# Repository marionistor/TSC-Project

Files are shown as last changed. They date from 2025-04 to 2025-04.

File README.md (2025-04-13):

# OpenBook

OpenBook este un e-book reader open-source, construit pentru consum mic de energie și versatilitate. Folosește microcontrollerul ESP32-C6-WROOM-1-N8, un ecran e-paper, senzori ambientali, ceas în timp real și stocare extinsă, alimentate de o baterie reîncărcabilă.

diagram

## Bill of Materials

| Componentă | Descriere | Link Achiziție | Documentație |
|---|---|---|---|
| ESP32-C6-WROOM-1-N8 | Microcontroler cu Wi-Fi 6, BLE 5.0 | [Mouser](https://ro.mouser.com/ProductDetail/Espressif-Systems/ESP32-C6-WROOM-1-N8) | [Datasheet](https://www.espressif.com/sites/default/files/documentation/esp32-c6-wroom-1_wroom-1u_datasheet_en.pdf) |
| BME680 | Senzor temperatură, umiditate, presiune, VOC | [Mouser](https://ro.mouser.com/ProductDetail/Bosch-Sensortec/BME680) | [Datasheet](https://www.bosch-sensortec.com/media/boschsensortec/downloads/datasheets/bst-bme680-ds001.pdf) |
| DS3231SN | Ceas în timp real | [Mouser](https://ro.mouser.com/ProductDetail/Analog-Devices/DS3231SN) | [Datasheet](https://www.analog.com/media/en/technical-documentation/data-sheets/DS3231.pdf) |
| W25Q512JVEIQ | Memorie Flash 64MB | [Mouser](https://ro.mouser.com/ProductDetail/Winbond/W25Q512JVEIQ) | [Datasheet](https://www.winbond.com/resource-files/W25Q512JV%20SPI%20RevB%2006252019%20KMS.pdf) |
| MicroSD Slot (112A-TAAR-R03) | Slot card microSD | [Mouser](https://ro.mouser.com/ProductDetail/Attend/112A-TAAR-R03) | [Datasheet](https://www.attend.com.tw/data/download/file/112A-TAAR-R03_Spec.pdf) |
| MCP73831T-5ACI/OT | Încărcător baterie | [Mouser](https://ro.mouser.com/ProductDetail/Microchip-Technology/MCP73831T-5ACI-OT) | [Datasheet](https://ww1.microchip.com/downloads/en/DeviceDoc/MCP73831-Family-Data-Sheet-DS20001984H.pdf) |
| MAX17048G+T10 | Indicator nivel baterie | [Mouser](https://ro.mouser.com/ProductDetail/Analog-Devices/MAX17048G%2BT10) | [Datasheet](https://www.analog.com/media/en/technical-documentation/data-sheets/MAX17048-MAX17049.pdf) |
| XC6220A331MR-G | Regulator 3.3V | [Mouser](https://ro.mouser.com/ProductDetail/Torex-Semiconductor/XC6220A331MR-G) | [Datasheet](https://www.torexsemi.com/file/xc6220/XC6220.pdf) |
| USB4110-GF-A | Conector USB-C | [Mouser](https://ro.mouser.com/ProductDetail/GCT/USB4110-GF-A) | [Datasheet](https://gct.co/files/drawings/usb4110.pdf) |
| CPH3225A | Supercondensator pentru ceas | [Mouser](https://ro.mouser.com/ProductDetail/Seiko-Instruments/CPH3225A) | [Datasheet](https://mm.digikey.com/Volume0/opasdata/d220001/medias/docus/6537/rev05-CPHCPM.pdf) |
| DMG2305UX-7 | MOSFET P-Channel | [Mouser](https://ro.mouser.com/ProductDetail/Diodes-Incorporated/DMG2305UX-7) | [Datasheet](https://www.diodes.com/assets/Datasheets/DMG2305UX.pdf) |
| SI1308EDL-T1-GE3 | MOSFET N-Channel | [Mouser](https://ro.mouser.com/ProductDetail/Vishay-Siliconix/SI1308EDL-T1-GE3) | [Datasheet](https://www.vishay.com/docs/63399/si1308edl.pdf) |
| USBLC6-2SC6Y | Protecție ESD USB | [Mouser](https://ro.mouser.com/ProductDetail/STMicroelectronics/USBLC6-2SC6Y) | [Datasheet](https://www.st.com/resource/en/datasheet/usblc6-2.pdf) |
| PGB1010603MR | Protecție ESD | [Mouser](https://ro.mouser.com/ProductDetail/Littelfuse/PGB1010603MR) | [Datasheet](https://www.littelfuse.com/~/media/electronics/datasheets/esd_protection/littelfuse_pulseguard_esd_pgb1_series_datasheet.pdf) |
| BD5229G-TR | Detector tensiune | [Mouser](https://ro.mouser.com/ProductDetail/ROHM-Semiconductor/BD5229G-TR) | [Datasheet](https://fscdn.rohm.com/en/products/databook/datasheet/ic/power/voltage_detector/bd52xxg-e.pdf) |
| FH34SRJ-24S-0.5SH(99) | Conector FFC/FPC e-paper | [Mouser](https://ro.mouser.com/ProductDetail/Hirose-Connector/FH34SRJ-24S-0.5SH99) | [Datasheet](https://www.hirose.com/product/document?clcode=&productname=&series=FH34SRJ&documenttype=Catalog&lang=en) |
| 744043680 | Inductor | [Mouser](https://ro.mouser.com/ProductDetail/Wurth-Elektronik/744043680) | [Datasheet](https://www.we-online.com/components/products/datasheet/744043680.pdf) |
| EVQPUJ02K | Buton tactil | [Mouser](https://ro.mouser.com/ProductDetail/Panasonic/EVQPUJ02K) | [Datasheet](https://www.lcsc.com/datasheet/lcsc_datasheet_2201121800_PANASONIC-EVQPUJ02K_C2936858.pdf) |
| KP-1608SURCK | LED indicator | [Mouser](https://ro.mouser.com/ProductDetail/Kingbright/KP-1608SURCK) | [Datasheet](https://media.elv.com/file/107153_led_surck1608_data.pdf) |

## Funcționalitate Hardware

### 1. Microcontroler ESP32-C6-WROOM-1-N8
* Rol: Gestionează toate funcțiile, de la afișaj la conectivitate wireless
* Specificații: Procesor 32-bit, 160 MHz, 512 KB SRAM, Wi-Fi 6, Bluetooth 5.0
* Conexiuni:
  * SPI: Conectează ecranul, memoria Flash și cardul SD
  * I²C: Interfațează senzorul, ceasul și indicatorul de baterie
  * GPIO: Controlează butoanele și alte funcții
  * UART: Utilizat pentru depanare
* Consum: 3.3V, sub 10 µA în mod repaus

### 2. Ecran E-Paper
* Tip: 7.5 inci, rezoluție 800x480 pixeli
* Conexiune: SPI, cu linii pentru date, control și stare
* Consum: 20-50 mA la reîmprospătare, aproape zero în mod static
* Rol: Afișează text clar, ideal pentru lectură prelungită

### 3. Stocare
* Memorie Flash (W25Q512JVEIQ):
  * Capacitate: 64 MB, conectată prin SPI
  * Scop: Stochează firmware și cărți
  * Consum: 10-20 mA
* Slot MicroSD:
  * Conexiune: SPI, pentru stocare suplimentară
  * Consum: 30-100 mA la citire/scriere

### 4. Ceas în Timp Real (DS3231SN)
* Conexiune: I2C, partajat cu alte module
* Consum: Sub 1 µA cu supercondensator
* Rol: Menține ora exactă pentru loguri sau programări

### 5. Senzor Ambiental (BME680)
* Măsurători: Temperatură, umiditate, presiune, compuși volatili
* Conexiune: I2C, viteză de 400 kHz
* Consum: 0.8-3.6 mA în funcționare, sub 1 µA în repaus
* Rol: Monitorizează mediul pentru ajustări sau date

### 6. Alimentare
* Baterie: Li-Po, 2500 mAh, 3.7V
* Încărcare: MCP73831, maxim 1A prin USB-C
* Monitorizare: MAX17048, consum ~50 µA
* Regulator: 3.3V stabil
* Protecție: Împotriva descărcărilor electrostatice și polarității greșite

### 7. Interfață Utilizator
* Butoane: Trei tactile pentru navigare
* LED: Indică starea dispozitivului

### 8. Extensii
* Conector Qwiic: Pentru senzori I2C suplimentari
* Pini GPIO: Pentru conectarea altor module

## Pini ESP32-C6

| Pin | Semnal | Funcție | Motiv |
|---|---|---|---|
| EN | RESET | Resetare sistem | Pin standard pentru resetare |
| IO0 | INT_RTC | Întrerupere RTC | Capacitate de întrerupere low-power |
| IO1 | 32KHZ | Ieșire ceas RTC 32 kHz | Asigură cronometrare precisă |
| IO2 | MISO | Intrare date SPI | Comun pentru magistrala SPI |
| IO3 | EPD_BUSY | Stare ocupat e-paper | Verifică disponibilitatea afișajului |
| IO4 | SS_SD | Selectare card SD | CS dedicat pentru card SD |
| IO5 | EPD_DC | Date/comenzi e-paper | Distinge datele de comenzi |
| IO6 | SCK | Ceas SPI | Semnal comun de ceas pentru SPI |
| IO7 | MOSI | Ieșire date SPI | Comun pentru periferice SPI |
| IO9 | IO/BOOT | Buton pornire | Inițiază modul boot sau pornire |
| IO10 | EPD_CS | Selectare e-paper | CS dedicat pentru afișaj |
| IO11 | FLASH_CS | Selectare Flash | CS dedicat pentru memoria Flash |
| IO12 | USB_D- | Date diferențiale USB - | Pin fix pentru USB |
| IO13 | USB_D+ | Date diferențiale USB + | Pin fix pentru USB |
| IO15 | IO/CHANGE | Buton schimbare pagină | Intrare utilizator pentru navigare |
| IO18 | RTC_RST | Resetare RTC | Resetare hardware pentru ceas |
| IO21 | SDA | Linie date I²C | Comun pentru senzori și RTC |
| IO22 | SCL | Linie ceas I²C | Semnal comun de ceas I²C |
| IO23 | EPD_RST | Resetare e-paper | Resetare hardware pentru afișaj |
| TXD0 | TX | Transmitere UART (depanare) | Punct test pentru depanare |
| RXD0 | RX | Recepție UART (depanare) | Punct test pentru depanare |

## Decizii de Proiectare

* Alimentare stabilă: Liniile de putere au fost trasate cu prioritate pentru a garanta o funcționare fiabilă, restul semnalelor fiind optimizate automat.
* Conector USB-C: Configurat special pentru a elimina conflictele de design, permițând atât alimentare, cât și transfer de date.
* Afișaj e-paper: Ales pentru consum energetic minim și claritate, alimentat printr-un circuit dedicat cu tranzistor pentru eficiență.
* Extensibilitate: Include un port Qwiic și pini accesibili pentru viitoare modificări sau depanare ușoară.
* Protecție electrică: Adăugate circuite de siguranță pentru liniile de date și alimentare, asigurând rezistența dispozitivului.

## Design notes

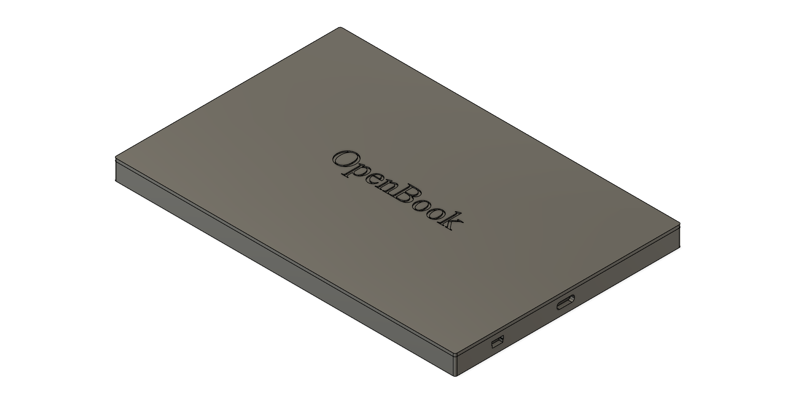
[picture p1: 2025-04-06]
Images/openbook_enclosure.png

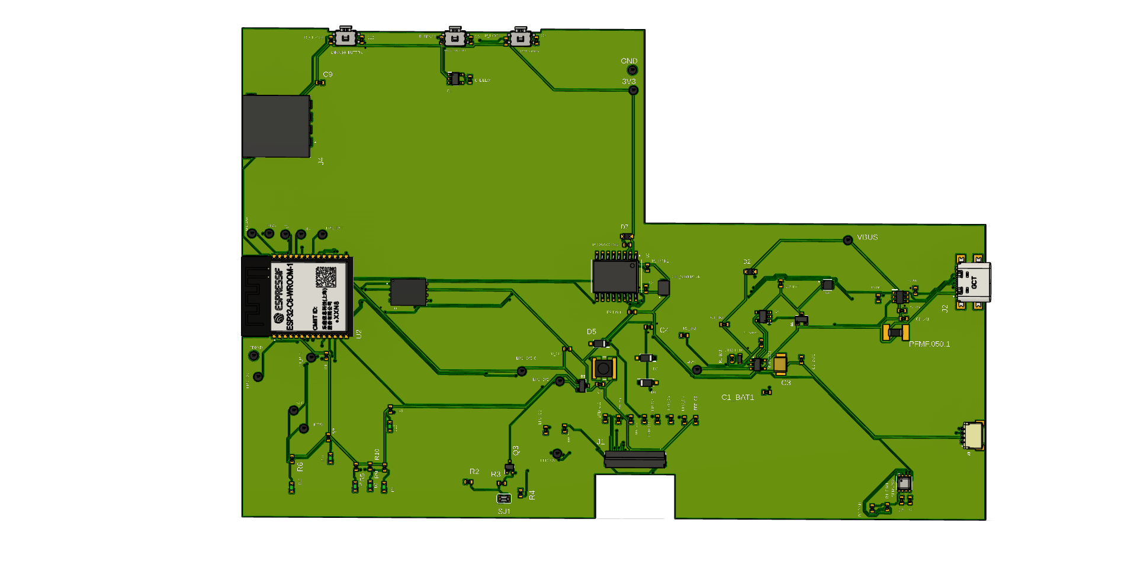
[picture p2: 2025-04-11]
Images/pcb_image1.png

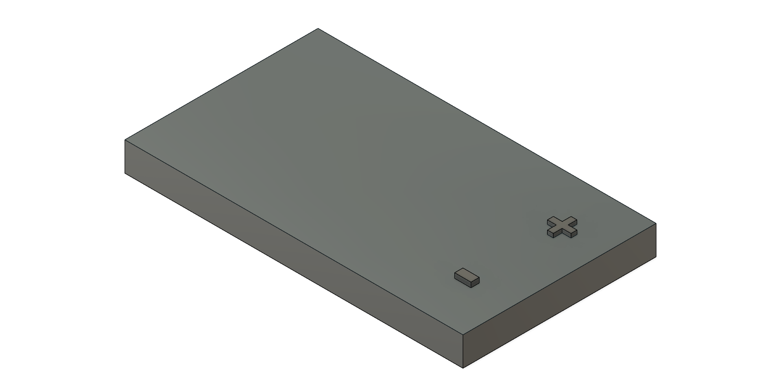
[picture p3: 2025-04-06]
Images/battery.png

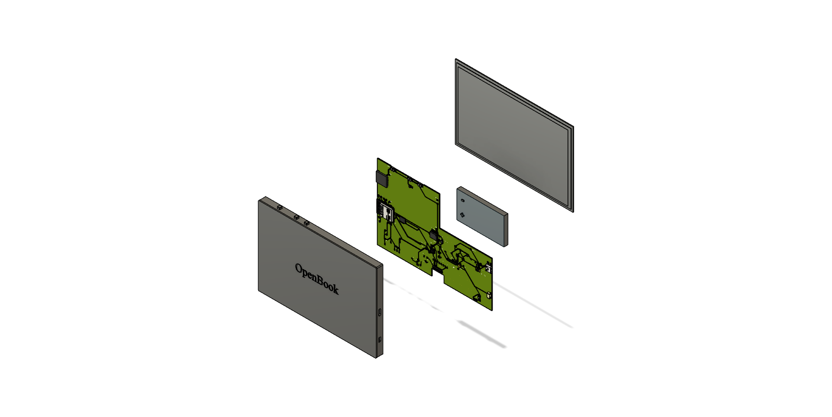
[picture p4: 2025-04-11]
Images/exploded_view.png

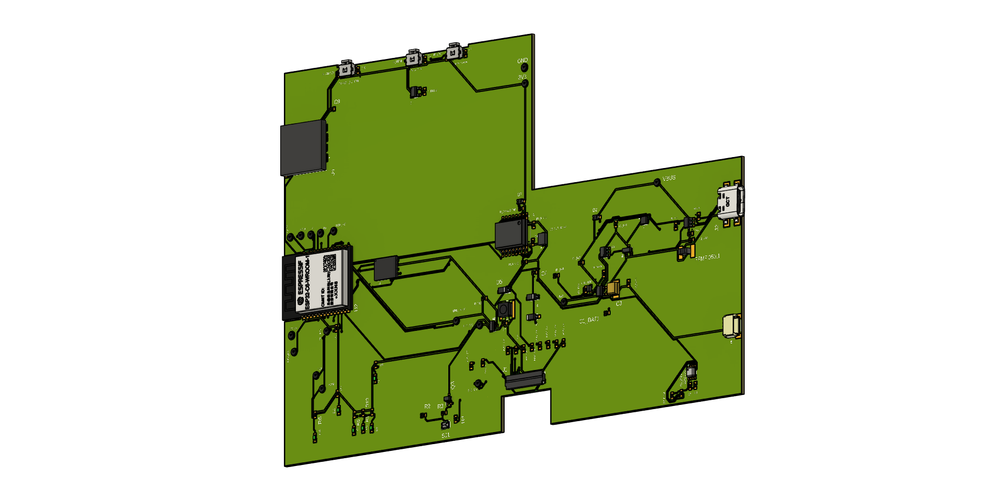
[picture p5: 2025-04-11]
Images/pcb_image2.png

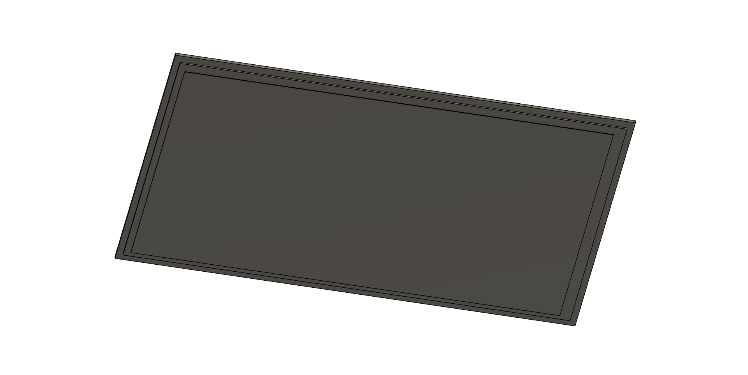
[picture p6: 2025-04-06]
Images/display.png

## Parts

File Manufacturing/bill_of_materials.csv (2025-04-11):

Qty | Value | Device | Package | Parts | Description | ARROW_PART_NUMBER | ARROW_PRICE-STOCK | AVAILABILITY | CENTROID_NOT_SPECIFIED | CHECK_PRICES | COPYRIGHT | DATASHEET | DESCRIPTION | DIGIKEY_DESCRIPTION | DIGIKEY_PART_NUMBER | HEIGHT | LEAD_FREE | MANUFACTURER_NAME | MANUFACTURER_PART_NUMBER | MF | MFR_NAME | MOUSER_PART_NUMBER | MOUSER_PRICE-STOCK | MOUSER_TESTING_PART_NUMBER | MOUSER_TESTING_PRICE-STOCK | MP | MPN | PACKAGE | POPULARITY | PREFIX | PRICE | PROD_ID | PURCHASE-URL | ROHS | SNAPEDA_LINK | SPICEMODEL | SPICEPREFIX | TEMPERATURE_RANGE_HIGH | TEMPERATURE_RANGE_LOW | TP_SIGNAL_NAME | VALUE
1 |  | ADAFRUIT_LEDCHIP-LED0603 | ADAFRUIT_CHIP-LED0603 | CHG_LED | LED
1 |  | SJ | SJ | SJ1 | SMD solder JUMPER |  |  |  |  |  |  |  |  |  |  |  |  |  |  |  |  |  |  |  |  |  |  |  | 3
1 | 0.1uF/50V | ESP32_WROVER_EAGLE-LTSPICE_CC0402 | ESP32_WROVER_EAGLE-LTSPICE_C0402 | EPD_C5 | CAPACITOR, European symbol |  |  |  |  |  |  |  |  |  |  |  |  |  |  |  |  |  |  |  |  |  |  |  |  |  |  |  |  |  |  | NONE | C
1 | 0.47 | ESP32_WROVER_EAGLE-LTSPICE_RR0402 | ESP32_WROVER_EAGLE-LTSPICE_R0402 | R3 | RESISTOR, European symbol |  |  |  |  |  |  |  |  |  |  |  |  |  |  |  |  |  |  |  |  |  |  |  |  |  |  |  |  |  |  | NONE | R
1 | 100k | ESP32_WROVER_EAGLE-LTSPICE_RR0402 | ESP32_WROVER_EAGLE-LTSPICE_R0402 | R1_PWRUSB | RESISTOR, European symbol |  |  |  |  |  |  |  |  |  |  |  |  |  |  |  |  |  |  |  |  |  |  |  |  |  |  |  |  |  |  | NONE | R
5 | 100nF | EAGLE-LTSPICE_CC0402 | EAGLE-LTSPICE_C0402 | C1, C2, C8, C9, C_DELAY | CAPACITOR, European symbol |  |  |  |  |  |  |  |  |  |  |  |  |  |  |  |  |  |  |  |  |  |  |  |  |  |  |  |  |  |  | NONE | C
3 | 100nF | ESP32_WROVER_EAGLE-LTSPICE_CC0402 | ESP32_WROVER_EAGLE-LTSPICE_C0402 | C4_USB, C6, C10 | CAPACITOR, European symbol |  |  |  |  |  |  |  |  |  |  |  |  |  |  |  |  |  |  |  |  |  |  |  |  |  |  |  |  |  |  | NONE | C
1 | 100uF TANT | RCL_CPOL-EUCT3528 | RCL_CT3528 | C3 | POLARIZED CAPACITOR, European symbol |  |  |  |  |  |  |  |  |  |  |  |  |  |  |  |  |  |  |  |  |  |  |  | 0 |  |  |  |  |  |  |  | C
16 | 10k | ESP32_WROVER_EAGLE-LTSPICE_RR0402 | ESP32_WROVER_EAGLE-LTSPICE_R0402 | R1, R1_PINH, R1_PINH1, R2-PINH, R2-PINH1, R4, R5, R6, R7, R8, R9, R10, R_BOOT, R_CHANGE, R_CL1, R_RESET | RESISTOR, European symbol |  |  |  |  |  |  |  |  |  |  |  |  |  |  |  |  |  |  |  |  |  |  |  |  |  |  |  |  |  |  | NONE | R
1 | 10uF | EAGLE-LTSPICE_CC0402 | EAGLE-LTSPICE_C0402 | C7 | CAPACITOR, European symbol |  |  |  |  |  |  |  |  |  |  |  |  |  |  |  |  |  |  |  |  |  |  |  |  |  |  |  |  |  |  | NONE | C
1 | 112A-TAAR-R03_ATTEND | 112A-TAAR-R03_ATTEND | 112ATAARR03ATTEND | J4 | Micro SD Card Socket, Push-Push Type, Top Mount, SMT, H=1.83mm, 10u |  |  |  |  |  |  |  | Micro SD Card Socket | Push-Push Type | Top Mount | SMT | H=1.83mm | 10u |  |  | 1.9mm |  | ATTEND | 112A-TAAR-R03 ATTEND
1 | 15 | ESP32_WROVER_EAGLE-LTSPICE_RR0402 | ESP32_WROVER_EAGLE-LTSPICE_R0402 | R_CAPACITOR | RESISTOR, European symbol |  |  |  |  |  |  |  |  |  |  |  |  |  |  |  |  |  |  |  |  |  |  |  |  |  |  |  |  |  |  | NONE | R
1 | 1uF | EAGLE-LTSPICE_CC0402 | EAGLE-LTSPICE_C0402 | C5 | CAPACITOR, European symbol |  |  |  |  |  |  |  |  |  |  |  |  |  |  |  |  |  |  |  |  |  |  |  |  |  |  |  |  |  |  | NONE | C
9 | 1uF/50V | ESP32_WROVER_EAGLE-LTSPICE_CC0402 | ESP32_WROVER_EAGLE-LTSPICE_C0402 | EPD_C1, EPD_C2, EPD_C6, EPD_C7, EPD_C8, EPD_C9, EPD_C10, EPD_C11, EPD_C12 | CAPACITOR, European symbol |  |  |  |  |  |  |  |  |  |  |  |  |  |  |  |  |  |  |  |  |  |  |  |  |  |  |  |  |  |  | NONE | C
1 | 2.2 | ESP32_WROVER_EAGLE-LTSPICE_RR0402 | ESP32_WROVER_EAGLE-LTSPICE_R0402 | R2 | RESISTOR, European symbol |  |  |  |  |  |  |  |  |  |  |  |  |  |  |  |  |  |  |  |  |  |  |  |  |  |  |  |  |  |  | NONE | R
1 | 200 | ESP32_WROVER_EAGLE-LTSPICE_RR0402 | ESP32_WROVER_EAGLE-LTSPICE_R0402 | R1_BAT | RESISTOR, European symbol |  |  |  |  |  |  |  |  |  |  |  |  |  |  |  |  |  |  |  |  |  |  |  |  |  |  |  |  |  |  | NONE | R
2 | 20V/4.2A/52mO/1.4W | ESP32_WROVER_SPARKFUN-DISCRETESEMI_MOSFET_PCH-DMG2305UX-7 | ESP32_WROVER_SPARKFUN-DISCRETESEMI_SOT23-3 | Q1, Q2 | P-channel MOSFETs |  |  |  |  |  |  |  |  |  |  |  |  |  |  |  |  |  |  |  |  |  |  |  |  |  |  | TRAN-14388 |  |  |  |  |  |  |  |  | 20V/4.2A/52mO/1.4W
1 | 2k | ESP32_WROVER_EAGLE-LTSPICE_RR0402 | ESP32_WROVER_EAGLE-LTSPICE_R0402 | R2_BAT | RESISTOR, European symbol |  |  |  |  |  |  |  |  |  |  |  |  |  |  |  |  |  |  |  |  |  |  |  |  |  |  |  |  |  |  | NONE | R
2 | 4.7uF | EAGLE-LTSPICE_CC0402 | EAGLE-LTSPICE_C0402 | C1_BAT1, C2_BAT | CAPACITOR, European symbol |  |  |  |  |  |  |  |  |  |  |  |  |  |  |  |  |  |  |  |  |  |  |  |  |  |  |  |  |  |  | NONE | C
3 | 4.7uF | ESP32_WROVER_EAGLE-LTSPICE_CC0402 | ESP32_WROVER_EAGLE-LTSPICE_C0402 | C1_BAT, C1_BAT2, C5_USB | CAPACITOR, European symbol |  |  |  |  |  |  |  |  |  |  |  |  |  |  |  |  |  |  |  |  |  |  |  |  |  |  |  |  |  |  | NONE | C
1 | 4.7uF/25V | EAGLE-LTSPICE_CC0402 | EAGLE-LTSPICE_C0402 | C4 | CAPACITOR, European symbol |  |  |  |  |  |  |  |  |  |  |  |  |  |  |  |  |  |  |  |  |  |  |  |  |  |  |  |  |  |  | NONE | C
2 | 5k1 | ESP32_WROVER_EAGLE-LTSPICE_RR0402 | ESP32_WROVER_EAGLE-LTSPICE_R0402 | R2-USB, R2-USB1 | RESISTOR, European symbol |  |  |  |  |  |  |  |  |  |  |  |  |  |  |  |  |  |  |  |  |  |  |  |  |  |  |  |  |  |  | NONE | R
1 | 68uH | 744043680IND_4828-WE-TPC_WRE | IND_4828-WE-TPC_WRE | L1 |  |  |  |  |  |  | Copyright (C) 2024 Ultra Librarian. All rights reserved. |  |  |  |  |  |  |  | 744043680 |  | Wurth Electronics
1 | BD5229G-TR | BD5229G-TR | SOT95P280X125-5N | IC1 | Voltage Detector with Adjustable Delay Time: CMOS processes are utilized to develop high precision, low current consumption CMOS reset ICs that allow arbitrary setting of the delay time. The extensive lineup includes both Nch Open Drain and CMOS output types in a wide range of detection voltages (from 2.3V to 6.0V, in 0.1V steps), enabling selection of the ideal solution based on customer requirements. In addition, the entire series is of course both lead-free and RoHS-compliant. |  |  |  |  |  |  |  | Voltage Detector with Adjustable Delay Time: CMOS processes are utilized to develop high precision | low current consumption CMOS reset ICs that allow arbitrary setting of the delay time. The extensive lineup includes both Nch Open Drain and CMOS output types in a wide range of detection voltages (from 2.3V to 6.0V | in 0.1V steps) | enabling selection of the ideal solution based on customer requirements. In addition | the entire series is of course both lead-free and RoHS-compliant. |  |  | 1.25mm |  | ROHM Semiconductor | BD5229G-TR |  |  | 755-BD5229G-TR | https://www.mouser.co.uk/ProductDetail/ROHM-Semiconductor/BD5229G-TR?qs=4kLU8WoGk0vvnhrrYwdszw%3D%3D
3 | BUTTON_CUSYOMV1 | BUTTON_CUSYOMV1 | MYBUTTON | BOOT_BUTTON, CHANGE_BUTTON, RESET_BUTTON
1 | CPH3225A | CPH3225A | CAPCP3225X100N | C10_SUPERCAP | Cap 0.011F 3.3V 1210 Flat Check availability |  |  | Not in stock |  | https://www.snapeda.com/parts/CPH3225A/Seiko+Instruments/view-part/?ref=eda |  |  | 11 mF (EDLC) Supercapacitor 3.3 V 1210 (3225 Metric) - - |  |  |  |  |  |  | Seiko Instruments |  |  |  |  |  | CPH3225A |  | 1210 Seiko |  |  | None |  | https://www.snapeda.com/api/url_track_click_mouser/?unipart_id=562593&manufacturer=Seiko Instruments&part_name=CPH3225A&search_term=None |  | https://www.snapeda.com/parts/CPH3225A/Seiko+Instruments/view-part/?ref=snap
1 | DS3231SN# | DS3231SN# | SOIC127P1032X265-16N | U3 | Real Time Clock Serial 16-Pin SOIC W T/R Check availability |  |  | In Stock |  | https://www.snapeda.com/parts/DS3231SN%23/Analog+Devices/view-part/?ref=eda |  |  | Extremely Accurate I²C-Integrated RTC/TCXO/Crystal |  |  |  |  |  |  | Analog Devices |  |  |  |  |  | DS3231SN# |  | SOIC-16 Maxim |  |  | None |  | https://www.snapeda.com/api/url_track_click_mouser/?unipart_id=99048&manufacturer=Analog Devices&part_name=DS3231SN#&search_term=None |  | https://www.snapeda.com/parts/DS3231SN%23/Analog+Devices/view-part/?ref=snap
1 | ESP32-C6-WROOM-1-N8 | ESP32-C6-WROOM-1-N8 | XCVR_ESP32-C6-WROOM-1-N8 | U2 | Check availability |  |  | In Stock |  | https://www.snapeda.com/parts/ESP32-C6-WROOM-1-N8/Espressif+Systems/view-part/?ref=eda |  |  | Multiprotocol Modules ESP32-C6 module | Wi-Fi 6 in 2.4 GHz band | Bluetooth 5 | Zigbee 3.0 and Thread. ESP34-WROOM Compatible - ENGINEERING SAMPLE |  |  |  |  |  |  | Espressif Systems |  |  |  |  |  | ESP32-C6-WROOM-1-N8 |  | None |  |  | None |  |  |  | https://www.snapeda.com/parts/ESP32-C6-WROOM-1-N8/Espressif+Systems/view-part/?ref=snap
1 | ESP32C6_VARISTORCN1812 | ESP32C6_VARISTORCN1812 | ESP32C6_VARISTOR_CT/CN1812 | PFMF.050.1 | VARISTOR |  |  |  |  |  |  |  |  |  |  |  |  |  |  |  |  |  |  |  |  |  |  |  | 0
2 | ESP32_WROVER_AVX---SD0805S020S1R0_AVX_SD0805S020S1R0_0_0AVX_SD0805S020S1R0_0_0 | ESP32_WROVER_AVX---SD0805S020S1R0_AVX_SD0805S020S1R0_0_0AVX_SD0805S020S1R0_0_0 | ESP32_WROVER_AVX---SD0805S020S1R0_AVX_SD0805S020S1R0_0 | D2, D7 | Schottky Barrier Rectifier Diode |  |  |  | No |  |  | http://datasheets.avx.com/schottky.pdf |  | DIODE SCHOTTKY 20V 1A 0805 | 478-7800-1-ND |  | yes |  |  | AVX |  | 581-SD0805S020S1R0 |  |  |  |  |  | 0805 (2012 metric) |  | D |  |  |  | yes |  |  |  | +125°C | -55°C
1 | ESP32_WROVER_BME680_BME680 | ESP32_WROVER_BME680_BME680 | ESP32_WROVER_BME680_PSON80P300X300X100-8N | SENSOR2 | Integrated Environmental Unit |  |  | Unavailable |  |  |  |  | Integrated Environmental Unit |  |  |  |  |  |  | Bosch Sensortec |  |  |  |  |  | BME680 |  | LGA-8 Bosch Tools |  |  | None
1 | ESP32_WROVER_SPARKFUN-IC-POWER_MCP73831 | ESP32_WROVER_SPARKFUN-IC-POWER_MCP73831 | ESP32_WROVER_SPARKFUN-IC-POWER_SOT23-5 | MCP73831 | MCP73831T Li-Ion, Li-Pol Controller |  |  |  |  |  |  |  |  |  |  |  |  |  |  |  |  |  |  |  |  |  |  |  |  |  |  | IC-09995
1 | FH34SRJ-24S-0.5SH_99_ | FH34SRJ-24S-0.5SH_99_ | FH34SRJ24S05SH99 | J1 | (0.50mm) Surface Mount, Right Angle |  |  |  |  |  |  |  | 24 Position FFC | FPC Connector Contacts | (0.50mm) Surface Mount | Right Angle |  |  | 1.1mm |  | Hirose | FH34SRJ-24S-0.5SH(99) |  |  | 798-FH34SRJ24S05SH99 | https://www.mouser.co.uk/ProductDetail/Hirose-Connector/FH34SRJ-24S-0.5SH99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
1 | MAX17048G+T10 | MAX17048G+T10 | SON50P200X200X80-9N | U4 | Check availability |  |  | In Stock |  | https://www.snapeda.com/parts/MAX17048G+T10/Analog+Devices/view-part/?ref=eda |  |  | 3µA 1-Cell/2-Cell Fuel Gauge with ModelGauge |  |  |  |  |  |  | Analog Devices |  |  |  |  |  | MAX17048G+T10 |  | TDFN-8 Maxim |  |  | None |  | https://www.snapeda.com/api/url_track_click_mouser/?unipart_id=329239&manufacturer=Analog Devices&part_name=MAX17048G+T10&search_term=None |  | https://www.snapeda.com/parts/MAX17048G+T10/Analog+Devices/view-part/?ref=snap
3 | MBR0530 | MBR0530 | SOD3716X135N | D3, D4, D5 | ON SEMICONDUCTOR - MBR0530 - DIODE, SCHOTTKY, 0.5A, 30V, SOD-123 |  |  | In Stock |  | https://www.snapeda.com/parts/MBR0530/Onsemi/view-part/?ref=eda |  |  | Diode Schottky 30 V 500mA Surface Mount SOD-123 |  |  |  |  |  |  | ON Semiconductor |  |  |  |  |  | MBR0530 |  | SOD-123-2 ON Semiconductor |  |  | None |  | https://www.snapeda.com/api/url_track_click_mouser/?unipart_id=179458&manufacturer=ON Semiconductor&part_name=MBR0530&search_term=None |  | https://www.snapeda.com/parts/MBR0530/Onsemi/view-part/?ref=snap
6 | PGB1010603MR | PGB1010603MR | DIOC1608X36N | D6, D8, D9, D10, D11, D12 | Check availability |  |  | In Stock |  | https://www.snapeda.com/parts/PGB1010603MR/Littelfuse/view-part/?ref=eda |  |  | 150V (Typ) Clamp - Ipp Tvs Diode Surface Mount 0603 (1608 Metric) |  |  |  |  |  |  | Littelfuse Inc. |  |  |  |  |  | PGB1010603MR |  | 0603 Littelfuse Inc. |  |  | None |  | https://www.snapeda.com/api/url_track_click_mouser/?unipart_id=5659453&manufacturer=Littelfuse Inc.&part_name=PGB1010603MR&search_term=None |  | https://www.snapeda.com/parts/PGB1010603MR/Littelfuse/view-part/?ref=snap
1 | QWIIC_RIGHT_ANGLE | QWIIC_CONNECTORJS-1MM | JST04_1MM_RA | J3 | SparkFun I2C Standard Qwiic Connector |  |  |  |  |  |  |  |  |  |  |  |  |  |  |  |  |  |  |  |  |  |  |  |  |  |  | CONN-13694 |  |  |  |  |  |  |  |  | QWIIC_RIGHT_ANGLE
1 | SAMACSYS_PARTS_USB4110-GF-A | SAMACSYS_PARTS_USB4110-GF-A | SAMACSYS_PARTS_USB4110GFA | J2 | CONN USB 2.0 TYPE-C R/A SMT |  |  |  |  |  |  |  | CONN USB 2.0 TYPE-C R/A SMT |  |  | 3.26mm |  | GCT (GLOBAL CONNECTOR TECHNOLOGY) | USB4110-GF-A |  |  | 640-USB4110-GF-A | https://www.mouser.co.uk/ProductDetail/GCT/USB4110-GF-A?qs=KUoIvG%2F9IlYiZvIXQjyJeA%3D%3D
1 | SI1308EDL-T1-GE3 | SI1308EDL-T1-GE3 | SOT65P210X110-3N | Q3 | MOSFET N-Ch 30V 1.5A TrenchFET SC70 Vishay Si1308EDL-T1-GE3 N-channel MOSFET Transistor, 1.5 A, 30 V, 3-Pin SC-70 |  |  | In Stock |  | https://www.snapeda.com/parts/SI1308EDL-T1-GE3/Vishay+Siliconix/view-part/?ref=eda |  |  | Si1308EDL-T1-GE3 N-channel MOSFET Transistor | 1.5 A | 30 V | 3-Pin SC-70 | Siliconix / Vishay SI1308EDL-T1-GE3 |  |  |  |  |  |  | Vishay Siliconix |  |  |  |  |  | SI1308EDL-T1-GE3 |  | SOT-323 Vishay Semiconductor |  |  | None |  | https://www.snapeda.com/api/url_track_click_mouser/?unipart_id=274603&manufacturer=Vishay Siliconix&part_name=SI1308EDL-T1-GE3&search_term=None |  | https://www.snapeda.com/parts/SI1308EDL-T1-GE3/Vishay+Siliconix/view-part/?ref=snap
17 | TPTP20R | TPTP20R | TP20R | 3V3, EPD_3V3, EPD_3V3_C, EPD_BUSY, EPD_CS, EPD_DC, EPD_RST, GND, INT_RTC, MISO, MOSI, RX, SCK, TPGND, TX, VBAT, VBUS | Test pad |  |  |  |  |  |  |  |  |  |  |  |  |  |  |  |  |  |  |  |  |  |  |  | 2
1 | USBLC6-2SC6Y | USBLC6-2SC6Y | SOT95P280X145-6N | D1 | Low Cap. ESD Protection Auto SOT-23-6 STMicroelectronics USBLC6-2SC6Y, Dual Uni-Directional TVS Diode Array, 6-Pin SOT-23 |  |  | In Stock |  | https://www.snapeda.com/parts/USBLC6-2SC6Y/STMicroelectronics/view-part/?ref=eda |  |  | 17V Clamp 5A (8/20µs) Ipp Tvs Diode Surface Mount SOT-23-6 |  |  |  |  |  |  | STMicroelectronics |  |  |  |  |  | USBLC6-2SC6Y |  | SOT-23-6 STMicroelectronics |  |  | None |  |  |  | https://www.snapeda.com/parts/USBLC6-2SC6Y/STMicroelectronics/view-part/?ref=snap
1 | W25Q512JVEIQ | W25Q512JVEIQ | SON127P600X800X80-9N | U1 | Check availability |  |  | In Stock |  | https://www.snapeda.com/parts/W25Q512JVEIQ/Winbond+Electronics/view-part/?ref=eda |  |  | FLASH - NOR Memory IC 512Mb (64M x 8) SPI - Quad I/O 133 MHz 8-WSON (8x6) |  |  |  |  |  |  | Winbond Electronics |  |  |  |  |  | W25Q512JVEIQ |  | Package |  |  | None |  |  |  | https://www.snapeda.com/parts/W25Q512JVEIQ/Winbond+Electronics/view-part/?ref=snap
1 | XC6220A331MR-G | XC6220A331MR-G | SOT95P280X120-5N | IC4 | LDO Voltage Regulators |  |  |  |  |  |  |  | LDO Voltage Regulators |  |  | 1.2mm |  | Torex | XC6220A331MR-G |  |  | 865-XC6220A331MR-G | https://www.mouser.co.uk/ProductDetail/Torex-Semiconductor/XC6220A331MR-G?qs=AsjdqWjXhJ8ZSWznL1J0gg%3D%3D

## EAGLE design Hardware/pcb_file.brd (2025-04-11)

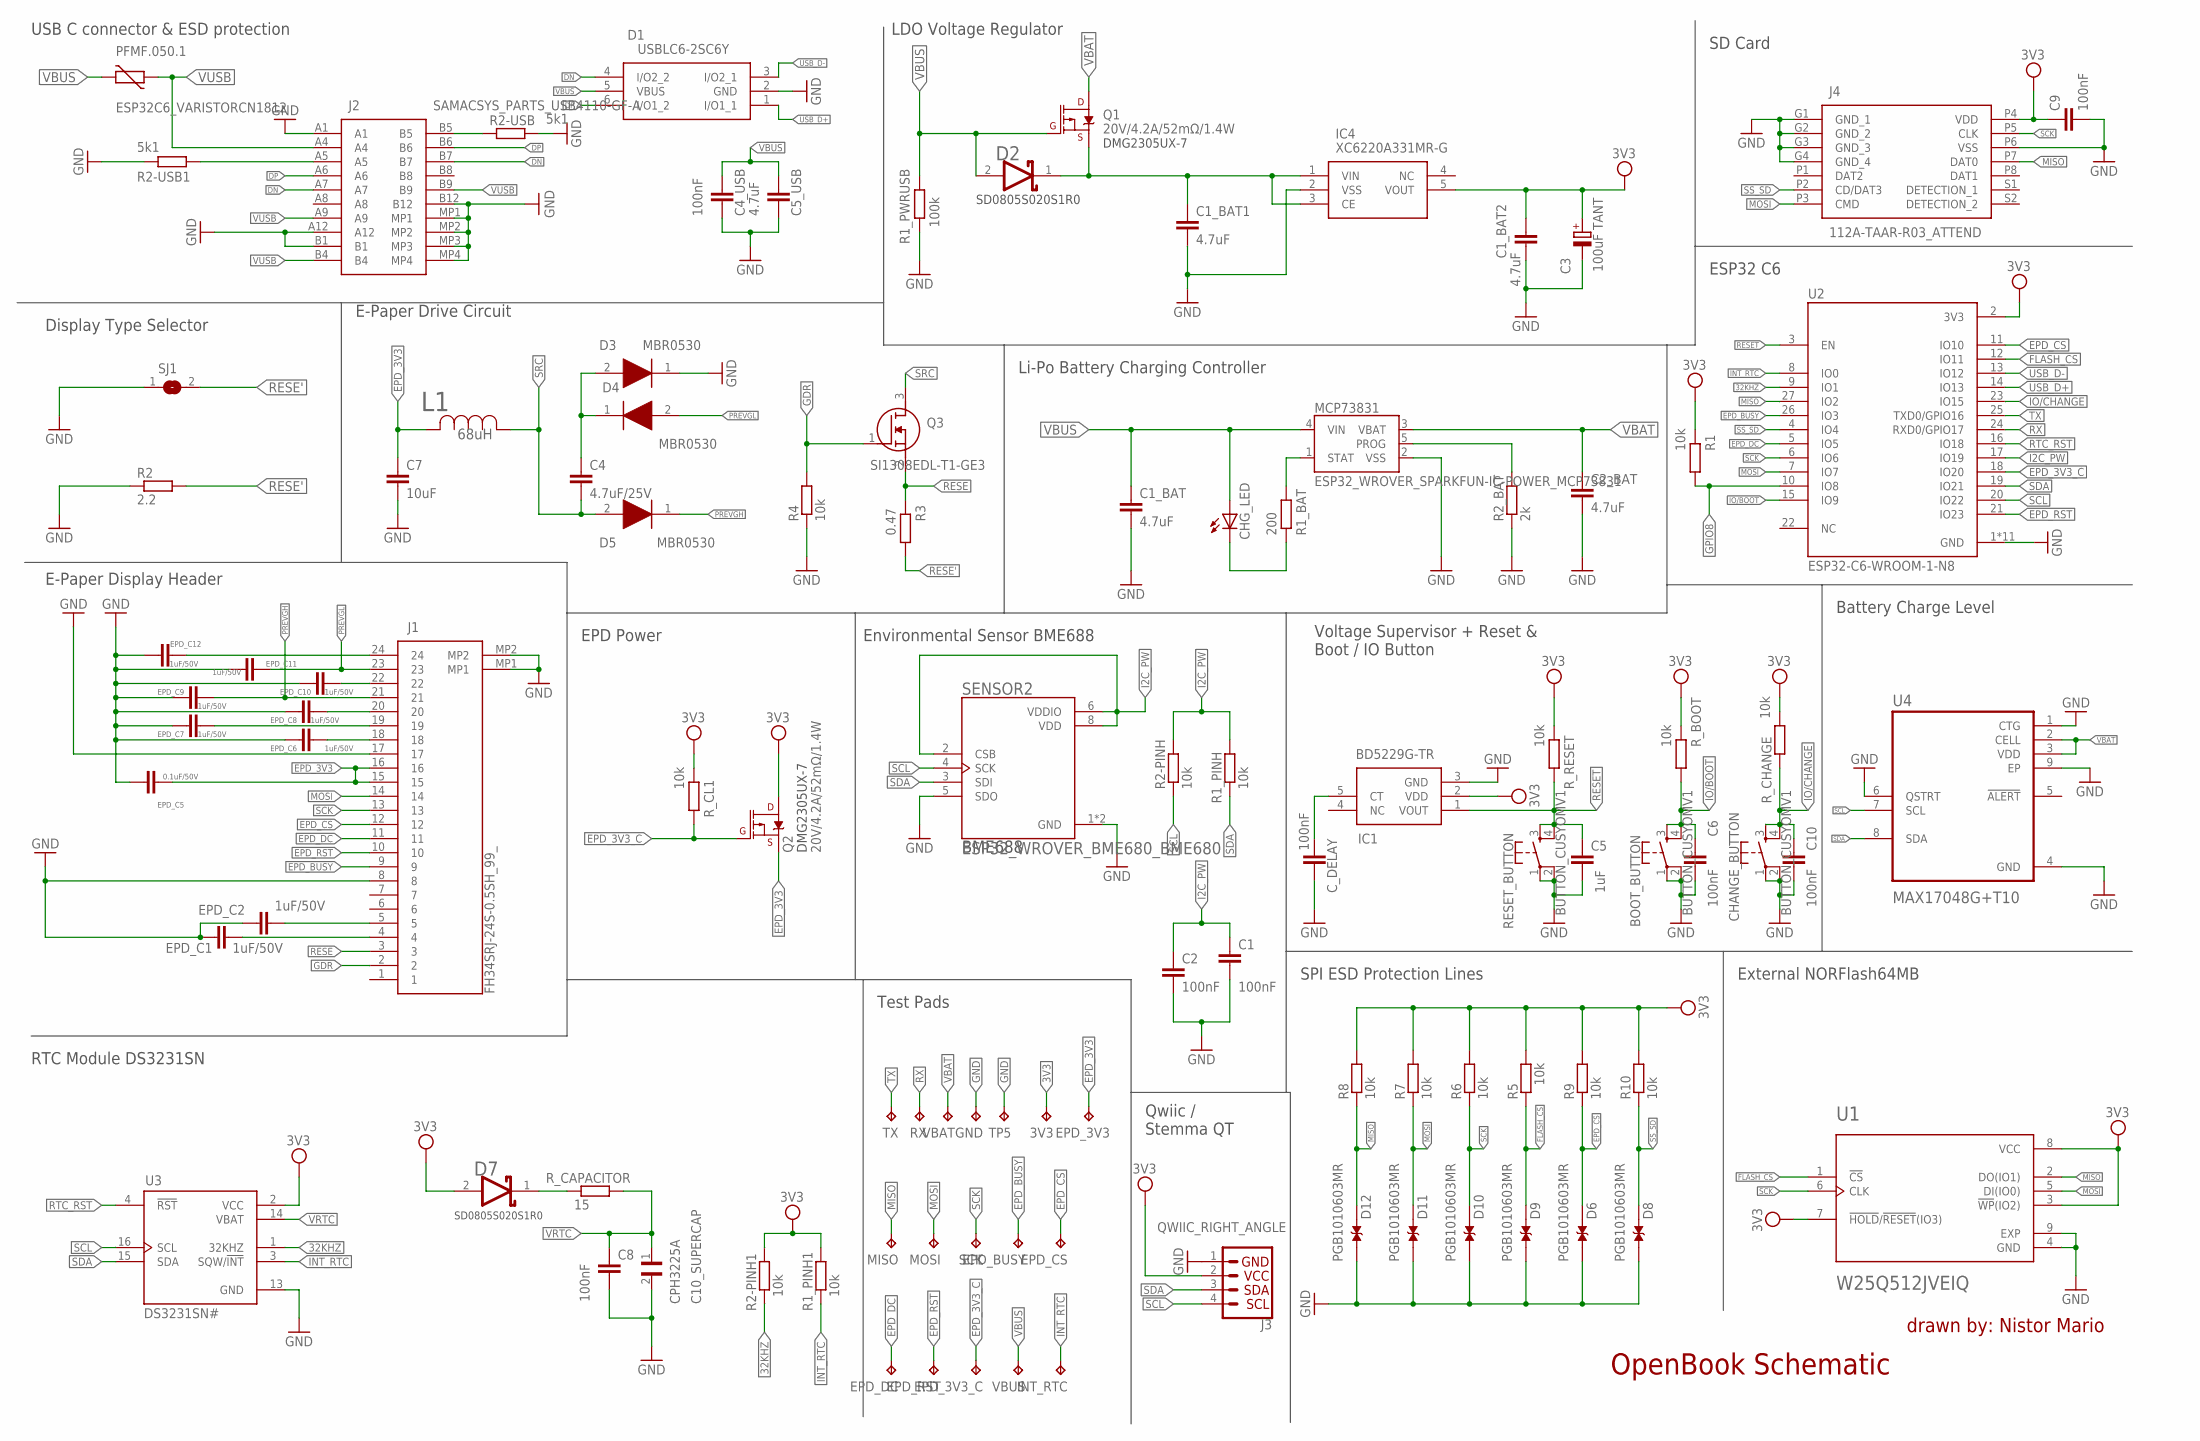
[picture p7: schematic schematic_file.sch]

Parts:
3V3: TPTP20R; TP20R
BOOT_BUTTON: BUTTON_CUSYOMV1; MYBUTTON
C1, C2, C8, C9: 100nF; EAGLE-LTSPICE_C0402
C1_BAT, C1_BAT2, C5_USB: 4.7uF; ESP32_WROVER_EAGLE-LTSPICE_C0402
C1_BAT1, C2_BAT: 4.7uF; EAGLE-LTSPICE_C0402
C3: 100uF TANT; RCL_CT3528
C4: 4.7uF/25V; EAGLE-LTSPICE_C0402
C4_USB, C6, C10: 100nF; ESP32_WROVER_EAGLE-LTSPICE_C0402
C5: 1uF; EAGLE-LTSPICE_C0402
C7: 10uF; EAGLE-LTSPICE_C0402
C10_SUPERCAP: CPH3225A; CAPCP3225X100N
CHANGE_BUTTON: BUTTON_CUSYOMV1; MYBUTTON
CHG_LED: ADAFRUIT_LEDCHIP-LED0603; ADAFRUIT_CHIP-LED0603
C_DELAY: 100nF; EAGLE-LTSPICE_C0402
D1: USBLC6-2SC6Y; SOT95P280X145-6N
D2, D7: ESP32_WROVER_AVX---SD0805S020S1R0_AVX_SD0805S020S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; ESP32_WROVER_AVX---SD0805S020S1R0_AVX_SD0805S020S1R0_0
D3, D4, D5: MBR0530; SOD3716X135N
D6, D8, D9, D10, D11, D12: PGB1010603MR; DIOC1608X36N
EPD_3V3, EPD_3V3_C: TPTP20R; TP20R
EPD_BUSY: TPTP20R; TP20R
EPD_C1, EPD_C2, EPD_C6, EPD_C7, EPD_C8, EPD_C9, EPD_C10, EPD_C11, EPD_C12: 1uF/50V; ESP32_WROVER_EAGLE-LTSPICE_C0402
EPD_C5: 0.1uF/50V; ESP32_WROVER_EAGLE-LTSPICE_C0402
EPD_CS: TPTP20R; TP20R
EPD_DC: TPTP20R; TP20R
EPD_RST: TPTP20R; TP20R
GND: TPTP20R; TP20R
IC1: BD5229G-TR; SOT95P280X125-5N
IC4: XC6220A331MR-G; SOT95P280X120-5N
INT_RTC: TPTP20R; TP20R
J1: FH34SRJ-24S-0.5SH_99_; FH34SRJ24S05SH99
J2: SAMACSYS_PARTS_USB4110-GF-A; SAMACSYS_PARTS_USB4110GFA
J3: QWIIC_RIGHT_ANGLE; JST04_1MM_RA
J4: 112A-TAAR-R03_ATTEND; 112ATAARR03ATTEND
L1: 68uH; IND_4828-WE-TPC_WRE
MCP73831: ESP32_WROVER_SPARKFUN-IC-POWER_MCP73831; ESP32_WROVER_SPARKFUN-IC-POWER_SOT23-5
MISO: TPTP20R; TP20R
MOSI: TPTP20R; TP20R
PFMF.050.1: ESP32C6_VARISTORCN1812; ESP32C6_VARISTOR_CT/CN1812
Q1, Q2: 20V/4.2A/52mΩ/1.4W; ESP32_WROVER_SPARKFUN-DISCRETESEMI_SOT23-3
Q3: SI1308EDL-T1-GE3; SOT65P210X110-3N
R1, R1_PINH, R1_PINH1, R2-PINH, R2-PINH1, R4, R5, R6, R7, R8, R9, R10: 10k; ESP32_WROVER_EAGLE-LTSPICE_R0402
R1_BAT: 200; ESP32_WROVER_EAGLE-LTSPICE_R0402
R1_PWRUSB: 100k; ESP32_WROVER_EAGLE-LTSPICE_R0402
R2: 2.2; ESP32_WROVER_EAGLE-LTSPICE_R0402
R2-USB, R2-USB1: 5k1; ESP32_WROVER_EAGLE-LTSPICE_R0402
R2_BAT: 2k; ESP32_WROVER_EAGLE-LTSPICE_R0402
R3: 0.47; ESP32_WROVER_EAGLE-LTSPICE_R0402
RESET_BUTTON: BUTTON_CUSYOMV1; MYBUTTON
RX: TPTP20R; TP20R
R_BOOT: 10k; ESP32_WROVER_EAGLE-LTSPICE_R0402
R_CAPACITOR: 15; ESP32_WROVER_EAGLE-LTSPICE_R0402
R_CHANGE: 10k; ESP32_WROVER_EAGLE-LTSPICE_R0402
R_CL1: 10k; ESP32_WROVER_EAGLE-LTSPICE_R0402
R_RESET: 10k; ESP32_WROVER_EAGLE-LTSPICE_R0402
SCK: TPTP20R; TP20R
SENSOR2: ESP32_WROVER_BME680_BME680; ESP32_WROVER_BME680_PSON80P300X300X100-8N
SJ1: SJ
TP5: TPTP20R; TP20R
TX: TPTP20R; TP20R
U1: W25Q512JVEIQ; SON127P600X800X80-9N
U2: ESP32-C6-WROOM-1-N8; XCVR_ESP32-C6-WROOM-1-N8
U3: DS3231SN#; SOIC127P1032X265-16N
U4: MAX17048G+T10; SON50P200X200X80-9N
VBAT: TPTP20R; TP20R
VBUS: TPTP20R; TP20R

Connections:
3V3: 3V3.TP, C1_BAT2.1, C3.+, C9.1, D7.2 (ANODE), IC1.2 (VDD), IC4.5 (VOUT), J3.2, J4.P4 (VDD), Q2.3 (D), R1.2, R1_PINH1.2, R2-PINH1.2, R5.2, R6.2, R7.2, R8.2, R9.2, R10.2, R_BOOT.2, R_CHANGE.2, R_CL1.2, R_RESET.2, U1.3 (!WP!(IO2)), U1.7 (!HOLD!/!RESET!(IO3)), U1.8 (VCC), U2.2 (3V3), U3.2 (VCC)
32KHZ: R2-PINH1.1, U2.9 (IO1), U3.1 (32KHZ)
DN: D1.4 (I/O2_2), J2.A7, J2.B7
DP: D1.6 (I/O1_2), J2.A6, J2.B6
EPD_3V3: C7.1, EPD_3V3.TP, EPD_C5.2, J1.15, J1.16, L1.2, Q2.2 (S)
EPD_3V3_C: EPD_3V3_C.TP, Q2.1 (G), R_CL1.1, U2.18 (IO20)
EPD_BUSY: EPD_BUSY.TP, J1.9, U2.26 (IO3)
EPD_CS: D6.2, EPD_CS.TP, J1.12, R9.1, U2.11 (IO10)
EPD_DC: EPD_DC.TP, J1.11, U2.5 (IO5)
EPD_RST: EPD_RST.TP, J1.10, U2.21 (IO23)
FLASH_CS: D9.2, R5.1, U1.1 (!CS), U2.12 (IO11)
GDR: J1.2, Q3.1 (G), R4.2
GND: BOOT_BUTTON.1, BOOT_BUTTON.2, C1.2, C1_BAT.2, C1_BAT1.2, C1_BAT2.2, C2.2, C2_BAT.2, C3.-, C4_USB.2, C5.2, C5_USB.2, C6.2, C7.2, C8.2, C9.2, C10.2, C10_SUPERCAP.2, CHANGE_BUTTON.1, CHANGE_BUTTON.2, C_DELAY.2, D1.2 (GND), D3.1 (K), D6.1, D8.1, D9.1, D10.1, D11.1, D12.1, EPD_C1.1, EPD_C2.1, EPD_C5.1, EPD_C6.1, EPD_C7.1, EPD_C8.1, EPD_C9.1, EPD_C10.1, EPD_C11.1, EPD_C12.1, GND.TP, IC1.3 (GND), IC4.2 (VSS), J1.8, J1.17, J1.MP1, J1.MP2, J2.A1, J2.A12, J2.B1, J2.B12, J2.MP1, J2.MP2, J2.MP3, J2.MP4, J3.1, J4.G1 (GND_1), J4.G2 (GND_2), J4.G3 (GND_3), J4.G4 (GND_4), J4.P6 (VSS), MCP73831.2 (VSS), R1_PWRUSB.2, R2.1, R2-USB.2, R2-USB1.1, R2_BAT.1, R4.1, RESET_BUTTON.1, RESET_BUTTON.2, SENSOR2.1 (GND), SENSOR2.5 (SDO), SENSOR2.7 (GND), SJ1.1, TP5.TP, U1.4 (GND), U1.9 (EXP), U2.1 (GND), U2.28 (GND), U2.29_1 (GND), U2.29_2 (GND), U2.29_3 (GND), U2.29_4 (GND), U2.29_5 (GND), U2.29_6 (GND), U2.29_7 (GND), U2.29_8 (GND), U2.29_9 (GND), U3.13 (GND), U4.1 (CTG), U4.4 (GND), U4.6 (QSTRT), U4.9 (EP); also elsewhere on the board
GPIO8: R1.1, U2.10 (IO8)
I2C_PW: C1.1, C2.1, R1_PINH.2, R2-PINH.2, SENSOR2.2 (CSB), SENSOR2.6 (VDDIO), SENSOR2.8 (VDD), U2.17 (IO19)
INT_RTC: INT_RTC.TP, R1_PINH1.1, U2.8 (IO0), U3.3 (SQW/!INT)
IO/BOOT: BOOT_BUTTON.3, BOOT_BUTTON.4, C6.1, R_BOOT.1, U2.15 (IO9)
IO/CHANGE: C10.1, CHANGE_BUTTON.3, CHANGE_BUTTON.4, R_CHANGE.1, U2.23 (IO15)
MISO: D12.2, J4.P7 (DAT0), MISO.TP, R8.1, U1.2 (DO(IO1)), U2.27 (IO2)
MOSI: D11.2, J1.14, J4.P3 (CMD), MOSI.TP, R7.1, U1.5 (DI(IO0)), U2.7 (IO7)
unnamed: J2.A5, R2-USB1.2
unnamed: J2.B5, R2-USB.1
unnamed: EPD_C1.2, J1.4
unnamed: C1_BAT1.1, D2.1 (CATHODE), IC4.1 (VIN), IC4.3 (CE), Q1.2 (S)
unnamed: EPD_C2.2, J1.5
unnamed: EPD_C12.2, J1.24
unnamed: MCP73831.1 (STAT), R1_BAT.2
unnamed: C4.1, D3.2 (A), D4.1 (K)
unnamed: EPD_C10.2, J1.22
unnamed: CHG_LED.C, R1_BAT.1
unnamed: MCP73831.5 (PROG), R2_BAT.2
unnamed: EPD_C8.2, J1.20
unnamed: EPD_C7.2, J1.19
unnamed: EPD_C6.2, J1.18
unnamed: C_DELAY.1, IC1.5 (CT)
unnamed: D7.1 (CATHODE), R_CAPACITOR.1
PREVGH: D5.1 (K), EPD_C9.2, J1.21
PREVGL: D4.2 (A), EPD_C11.2, J1.23
RESE: J1.3, Q3.2 (S), R3.2
RESE': R2.2, R3.1, SJ1.2
RESET: C5.1, IC1.1 (VOUT), RESET_BUTTON.3, RESET_BUTTON.4, R_RESET.1, U2.3 (EN)
RTC_RST: U2.16 (IO18), U3.4 (!RST)
RX: RX.TP, U2.24 (RXD0/GPIO17)
SCK: D10.2, J1.13, J4.P5 (CLK), R6.1, SCK.TP, U1.6 (CLK), U2.6 (IO6)
SCL: J3.4, R2-PINH.1, SENSOR2.4 (SCK), U2.20 (IO22), U3.16 (SCL), U4.7 (SCL)
SDA: J3.3, R1_PINH.1, SENSOR2.3 (SDI), U2.19 (IO21), U3.15 (SDA), U4.8 (SDA)
SRC: C4.2, D5.2 (A), L1.1, Q3.3 (D)
SS_SD: D8.2, J4.P2 (CD/DAT3), R10.1, U2.4 (IO4)
TX: TX.TP, U2.25 (TXD0/GPIO16)
USB_D+: D1.1 (I/O1_1), U2.14 (IO13)
USB_D-: D1.3 (I/O2_1), U2.13 (IO12)
VBAT: C2_BAT.1, MCP73831.3 (VBAT), Q1.3 (D), U4.2 (CELL), U4.3 (VDD), VBAT.TP
VBUS: C1_BAT.1, C4_USB.1, C5_USB.1, CHG_LED.A, D1.5 (VBUS), D2.2 (ANODE), MCP73831.4 (VIN), PFMF.050.1.2, Q1.1 (G), R1_PWRUSB.1, VBUS.TP
VRTC: C8.1, C10_SUPERCAP.1, R_CAPACITOR.2, U3.14 (VBAT)
VUSB: J2.A4, J2.A9, J2.B4, J2.B9, PFMF.050.1.1

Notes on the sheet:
USB C connector & ESD protection
LDO Voltage Regulator
SD0805S020S1R0
DMG2305UX-7
SD Card
Display Type Selector
E-Paper Display Header
E-Paper Drive Circuit
Li-Po Battery Charging Controller
ESP32 C6
EPD Power
BME688
Environmental Sensor BME688
Voltage Supervisor + Reset & Boot / IO Button
Battery Charge Level
RTC Module DS3231SN
Test Pads
Qwiic / Stemma QT
External NORFlash64MB
SPI ESD Protection Lines
OpenBook Schematic
drawn by: Nistor Mario

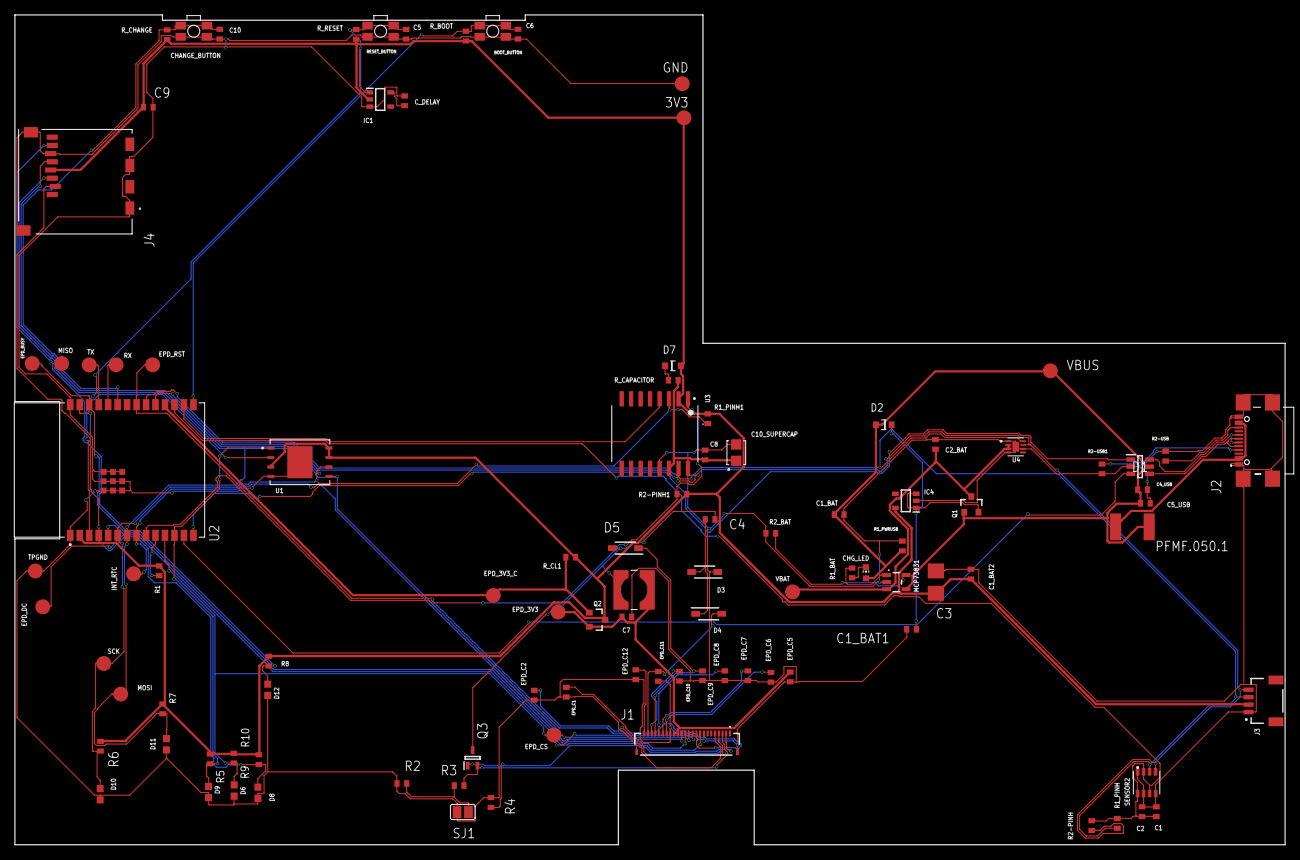
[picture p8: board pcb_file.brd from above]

Board: 2 copper layers, 170.2 x 111.2 mm, 103 parts (0 on the bottom side), 55 nets.

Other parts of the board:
TPGND: TPTP20R; TP20R

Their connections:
GND: TPGND.TP; also elsewhere on the board

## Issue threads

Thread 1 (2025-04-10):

Lipsă dimensiuni pe layer-ul „Measures” al PCB-ului

biancascirtocea, 2025-04-10:
Notatiile dimensiunilor plăcii nu sunt adăugate pe layer-ul Measures. Ar fi util sa le incluzi direct pe acel layer, pentru o verificare mai usoara.

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

Closed 2025-04-11.

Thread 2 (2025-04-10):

Semnalele de date nu respectă lățimea minimă de 0.15mm

biancascirtocea, 2025-04-10:
Conform cerințelor din documentație, traseele pentru semnalele de date ar trebui să aibă o lățime minimă de 0.15mm. În layout-ul actual, ele sunt de 0.13mm sub acest prag. E recomandat să fie ajustate pentru a evita pierderi de semnal sau interferențe. Poti face aceasta modificare din zona de design rules.

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

Closed 2025-04-11.

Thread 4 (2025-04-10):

Lipsă antet în fișierul PickAndPlace

biancascirtocea, 2025-04-10:
Conform instrucțiunilor de pe linkul de creare al fișierului PickAndPlace de pe ocw, ar trebui sa adaugi denumirile coloanelor pe prima linie a documentului astfel: Ref Des, Mid X (mm), Mid Y (mm), Rotation, Comment, Package, LCSC Part number.

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

Closed 2025-04-11.

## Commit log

2025-04-06 Added project files
    [bill_of_materials.csv, pcb_file.brd, pick_and_place.csv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]
2025-04-11 Fixed issues
    [bill_of_materials.csv, pcb_file.brd, pick_and_place.csv]

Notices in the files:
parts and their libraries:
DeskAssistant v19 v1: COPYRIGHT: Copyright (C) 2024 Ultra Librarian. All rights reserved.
